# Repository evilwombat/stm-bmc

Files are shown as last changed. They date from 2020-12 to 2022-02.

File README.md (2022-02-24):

# Summary

## What is bubble memory?
[Bubble memory](https://en.wikipedia.org/wiki/Bubble_memory]) is an archaic (yet super awesome) type of nonvolatile computer memory. It stores data as a pattern of magnetization on the surface of a crystal, in a manner loosely similar to a magnetic hard drive. The amazing thing about bubble memory is that despite being magnetic in nature, it uses **no moving parts**. Unlike a magnetic hard drive, the storage medium stays in place, but the *data* moves along its surface. This is accomplished through some magical properties of the [crystal](https://en.wikipedia.org/wiki/Gadolinium_gallium_garnet) involved. Bubble memory was a promising new storage technology in the 70s and 80s, due to (at the time) impressive densities, though it was ultimately replaced by cheaper and more reliable flash memories. 

## What is this project?
This is a controller for Bubble Memory modules made by Texas Instruments in the 1980s. I have brought this up using TIB S0004 memory modules. This is a reasonably functional controller, capable of reading, erasing, and writing data, though some of the analog circuitry could probably use some refinement. This was a quarantine project so I had to start with what I had at the time.

## Demo videos (click to play)

PCB version: http://www.youtube.com/watch?v=yxEgAI12R1k
Click to play (http://www.youtube.com/watch?v=yxEgAI12R1k "PCB version")

PCB (with explanation): http://www.youtube.com/watch?v=7U3c4cfQvKs
Click to play (http://www.youtube.com/watch?v=7U3c4cfQvKs "PCB version, with explanation")

Original, breadboarded version: http://www.youtube.com/watch?v=vP2biZnxT7Y
Click to play (http://www.youtube.com/watch?v=vP2biZnxT7Y "Breadboard version")

Honestly, I can't believe the breadboard version even worked cleanly enough for bringup. Notice the sense amplifier on a separate PCB.

## Implementation

Since bubble memory modules lack an internal controller, a fair amount of external circuitry is needed to produce the carefully-timed constant-current pulses needed to run them, and to amplify/process the output of the bubble detector. Historically, the timing of the control pulses was generated by a pile of logic circuits, or by a microsequencer. Later, both Intel and TI released some ICs to assist with this. Although today these are largely unobtanium, some documentation survives, including an [early design document](Research/DevelcoReport.pdf) that predates the existence of the integrated controller. The discrete-transistor implementation of the function pulse generator (and the associated timing information) found in this document is what made this project possible.

In modern times, the digital portion of such a controller can be reasonably implemented using a regular microcontroller, in this case, an STM32F103. The state machine and timing logic is handled entirely in firmware, but a fair amount of external circuitry is still needed to convert the logic-level signals into coil drive pulses and/or constant-current "function" pulses that are fed into the bubble module itself.

The STM32 firmware implements the following:
* Bubble function timing generator (Generate/Annihilate/Transfer)
* Coil drive timing generator
* Major/minor loop state machine
* Basic loop tests, for bringup/tuning of the analog circuit
* Block I/O layer (with CRC and trivial block redundancy)
* UI layer (LCD, fonts, graphics, rotary encoder)
* Bootloader to actually load code from the bubble memory and run it
* Proof-of-concept payload that can be loaded and booted
* [Morning Music](https://www.youtube.com/watch?v=tEueYGq2mT4) (obviously)

Although historical documentation exists, most of the detailed information pertains to an earlier prototype of TI bubble memory (TBM0101), one that was ultimately not commercialized. In the more widely-available parts (such as TIB0203 and the TIB-S0004 used here), some of the key operating parameters (such as drive cycle timings and function timings) have changed substantially. The correct parameters needed to be determined partly by trial and error, and partly by translating some old Russian datasheets relating to their knockoffs of TI's more modern bubble memory parts.

## Hardware Gallery

Assembled PCB version:
Assembled PCB running

Schematic:
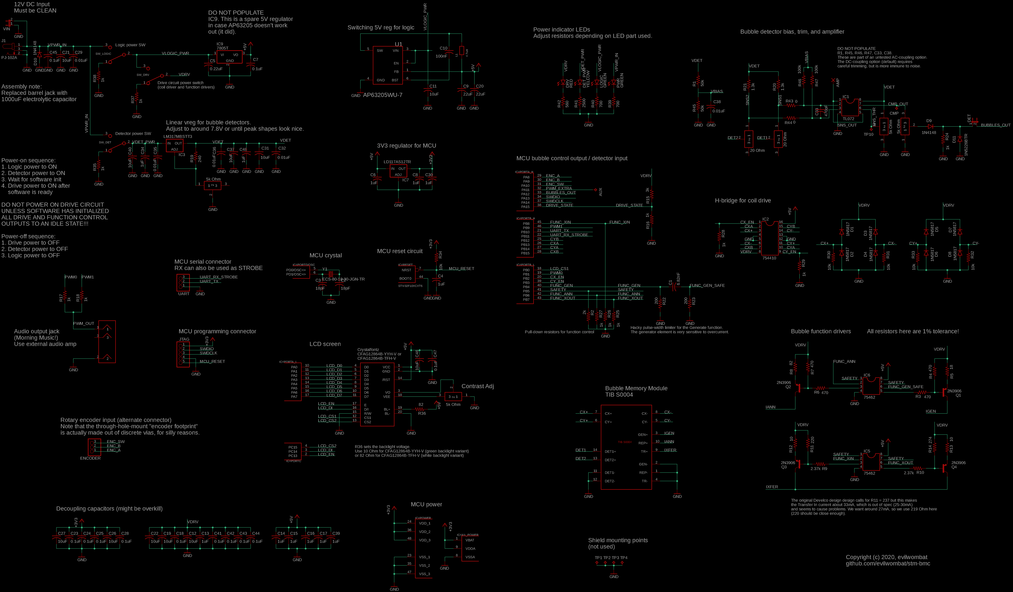
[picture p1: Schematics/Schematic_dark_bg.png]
Schematic


PCB layout:
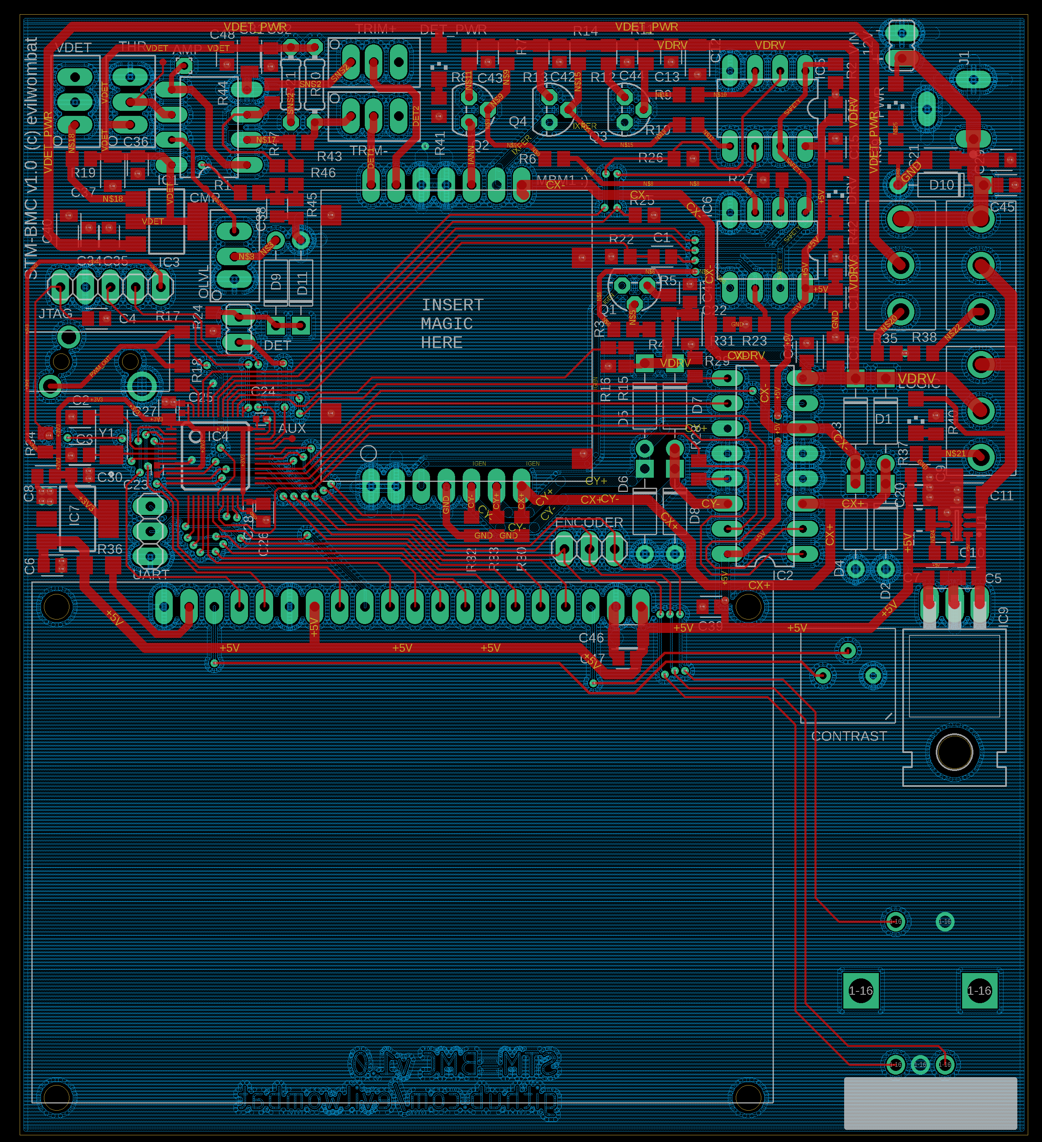
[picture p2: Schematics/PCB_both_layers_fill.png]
PCB Layout


First breadboarded version:
Full setup with breadboard

Close-up up of the breadboarded analog section. The amplifier circuit is too sensitive for breadboarding, and was built on a piece of perf-board. An alternate amplifier design would be less sensitive to minor variations in detector resistance, and hence would not need to many trimpots. But this design would be more sensitive to noise (which was much harder to control in a setup like this).
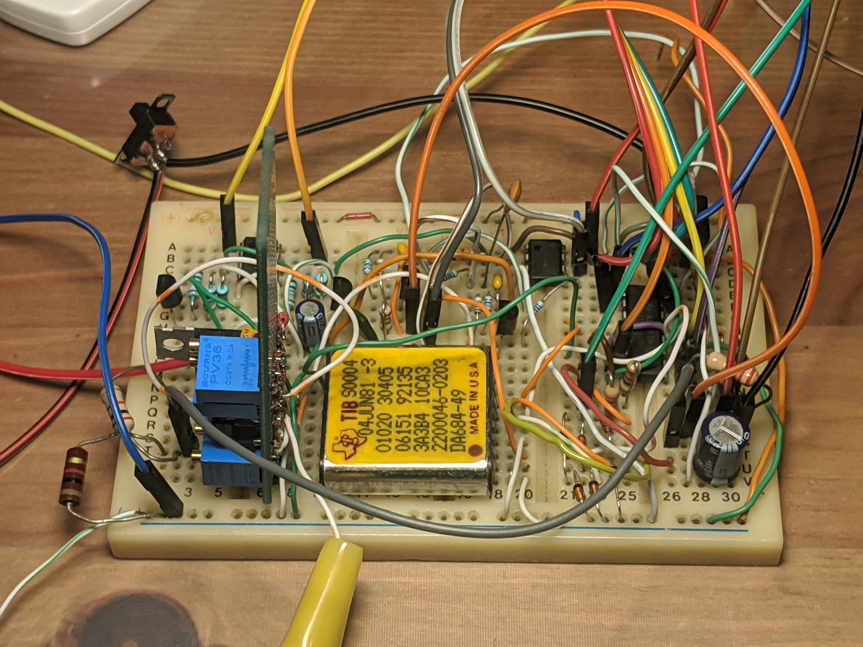
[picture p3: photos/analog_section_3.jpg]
Breadboard closeup


Some of the first bubbles!
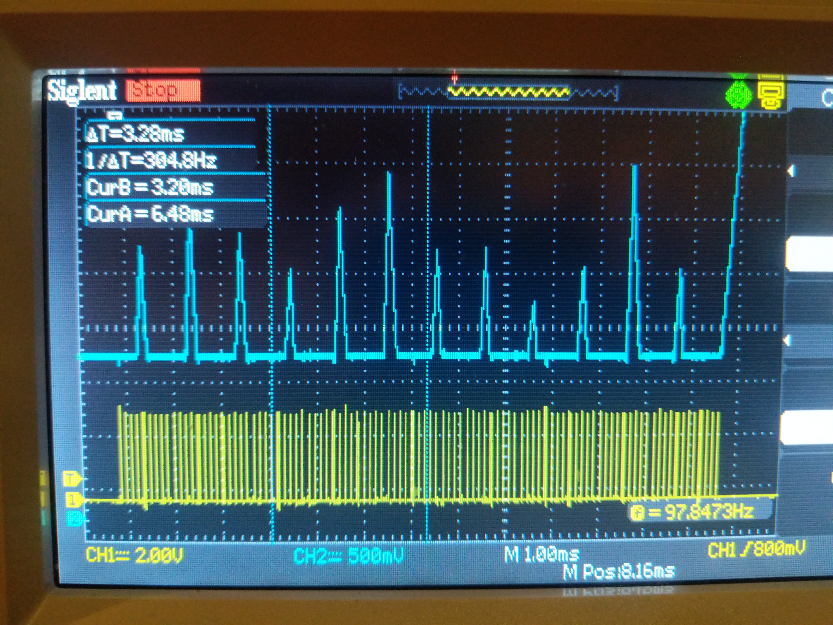
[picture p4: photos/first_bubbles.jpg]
Scope bubble trace


## What's with the music and countdown?

Perhaps the best-known example of a bubble memory design is Konami's famous [Bubble System](https://en.wikipedia.org/wiki/Bubble_System) arcade platform.

In 1985, Konami released a number of arcade machines that used bubble memory (rather than silicon ROM) for game storage. When switched on, these machines spoke a voice-based countdown while the memory modules were heated to their operating temperature. Since bubble memory is read slowly and sequentially, the game residing within was first copied into RAM before it could be executed; the machine displayed an [on-screen countdown](https://www.youtube.com/watch?v=mbM_YPyVJBE&t=175s) (and played an accompanying melody) during this process. The system was ultimately a commercial failure, because the bubble memory was expensive and very sensitive to external magnetic fields; meanwhile, silicon-based storage was growing cheaper. The few games that used this system were eventually re-released on ROM, but some original bubble-based systems survive to this day. 

<b>Fun fact:</b> The melody that played during the loading countdown was called the Morning Music, because it played every morning when the arcade operator switched on the machine. It has been said that the boot process was a kind of special / unusual thing to see, and that people would show up bright and early to the arcade just to watch the machines boot (and to listen to the morning music).

> Written with [StackEdit](https://stackedit.io/).

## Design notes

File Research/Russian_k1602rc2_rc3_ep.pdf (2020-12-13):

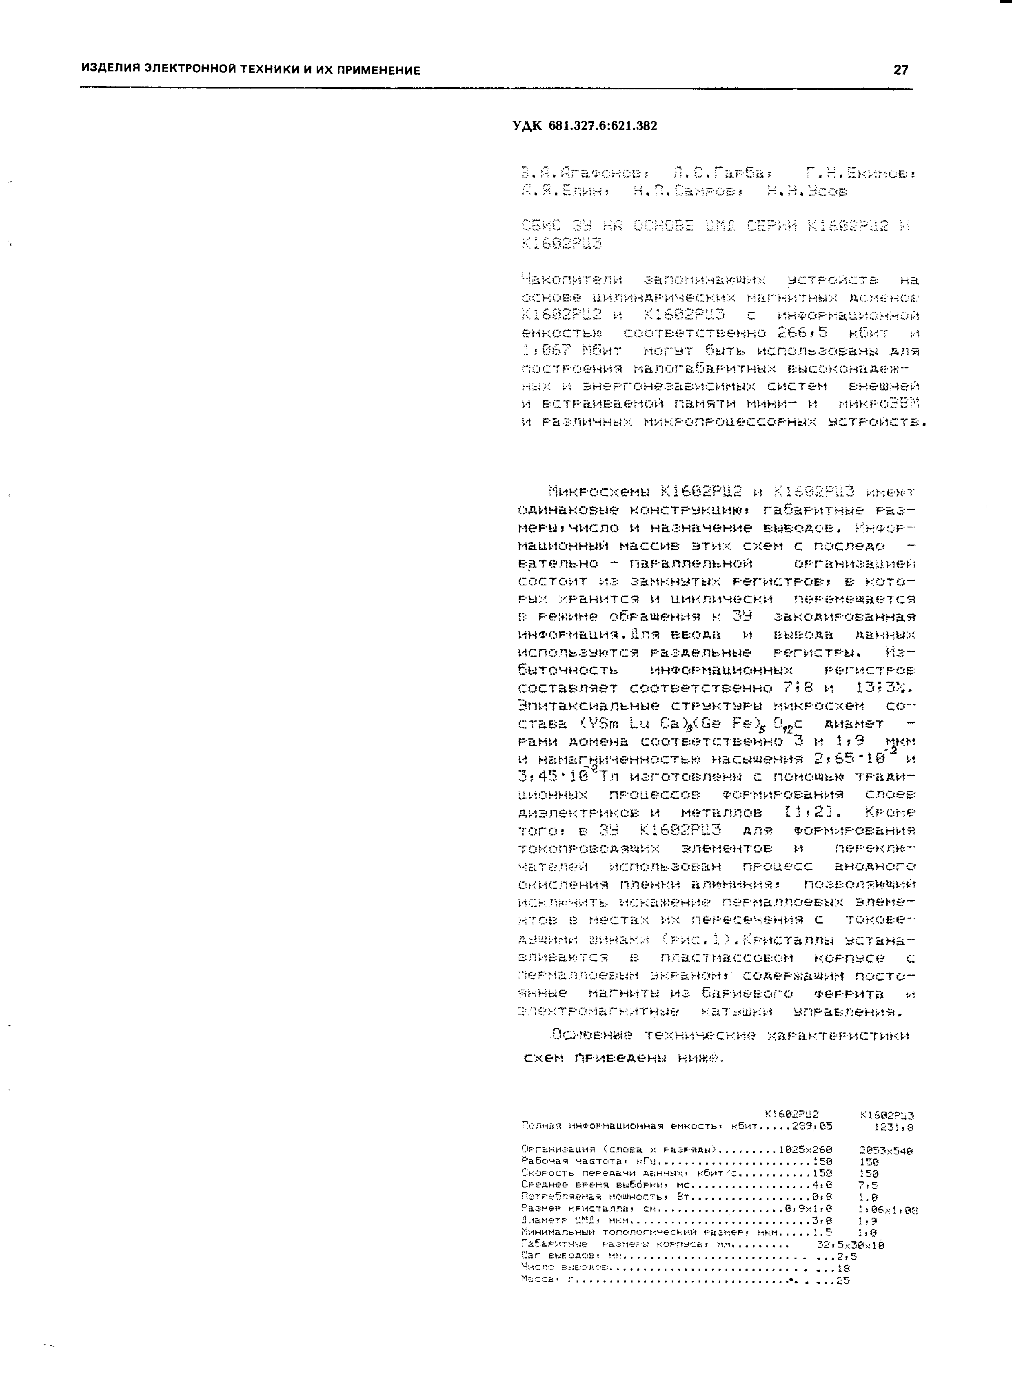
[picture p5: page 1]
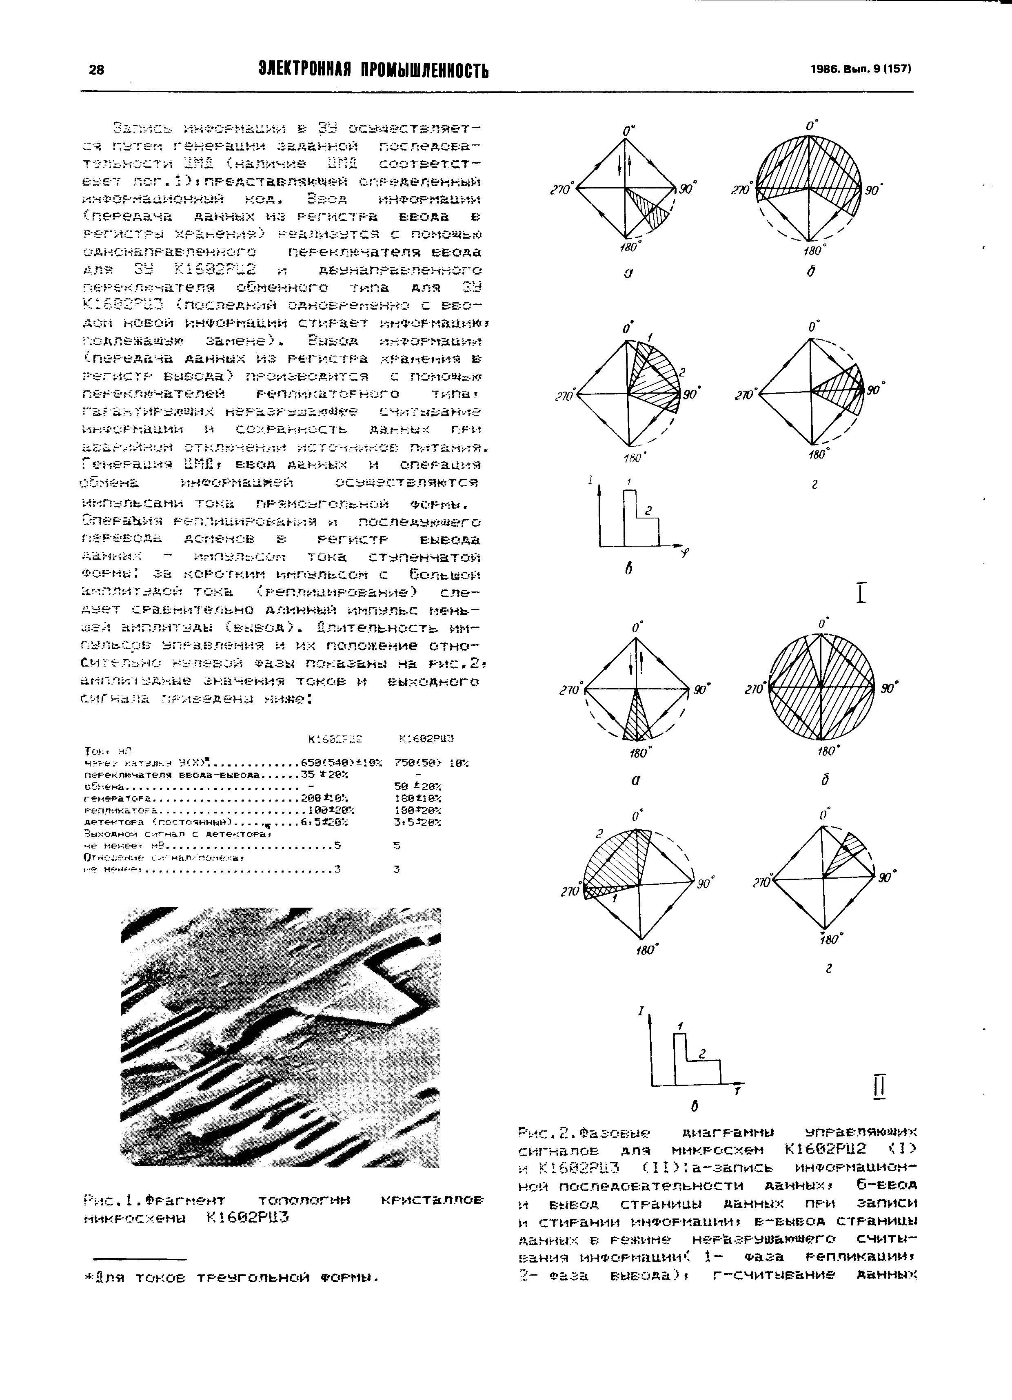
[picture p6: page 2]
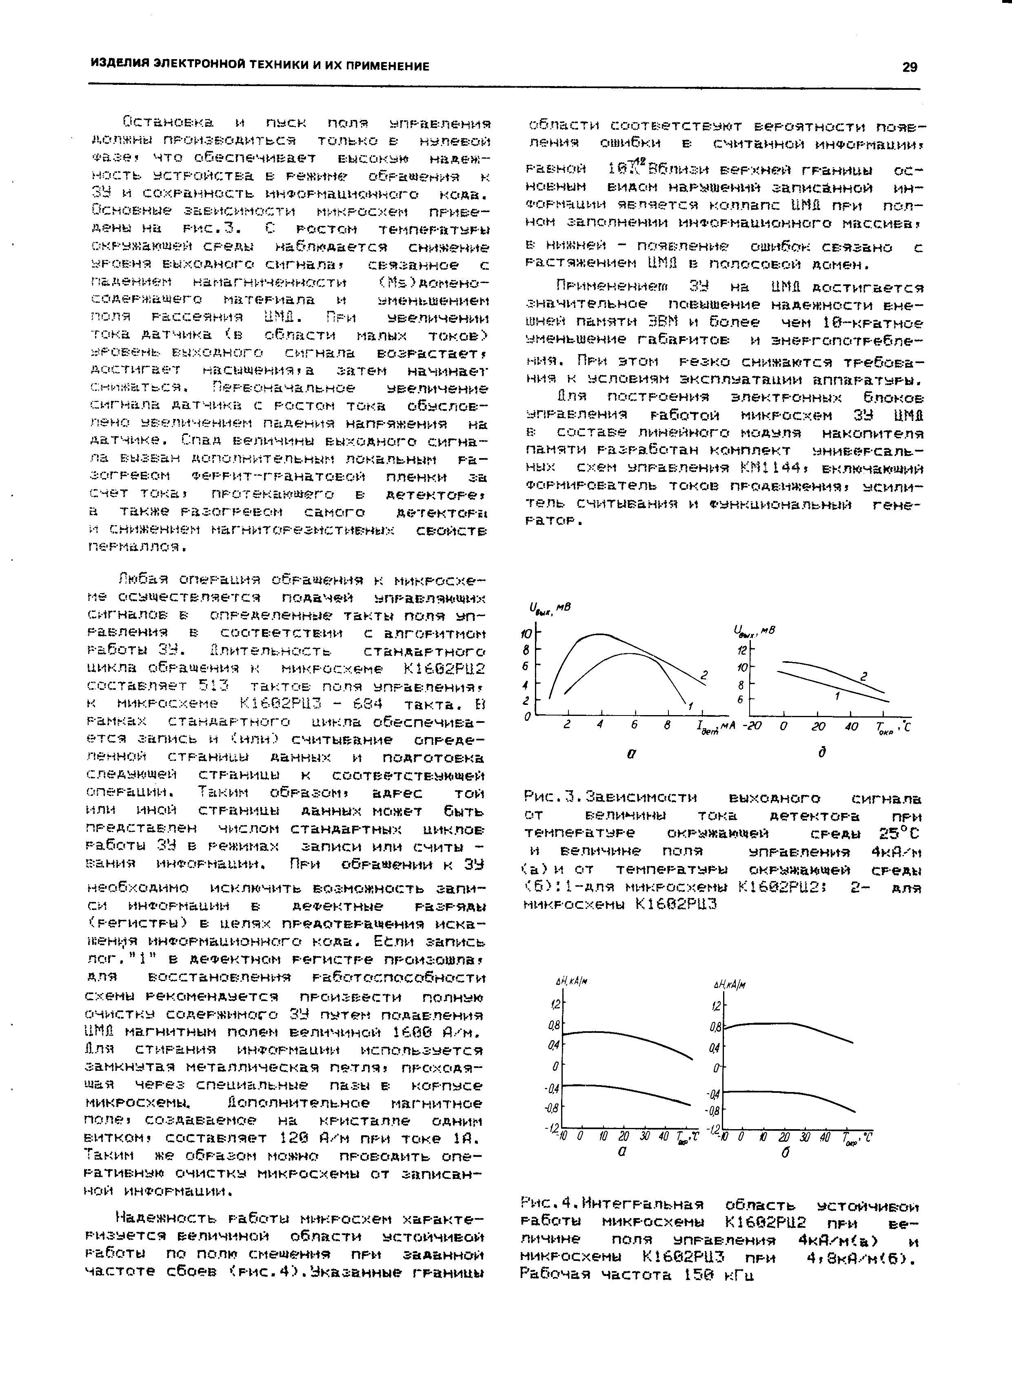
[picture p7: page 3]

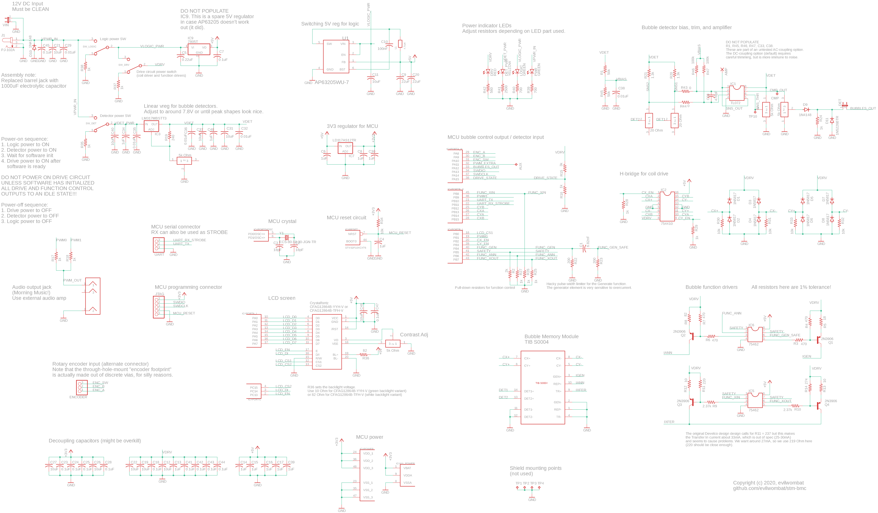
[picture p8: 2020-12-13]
Schematics/Schematic_light_bg.png

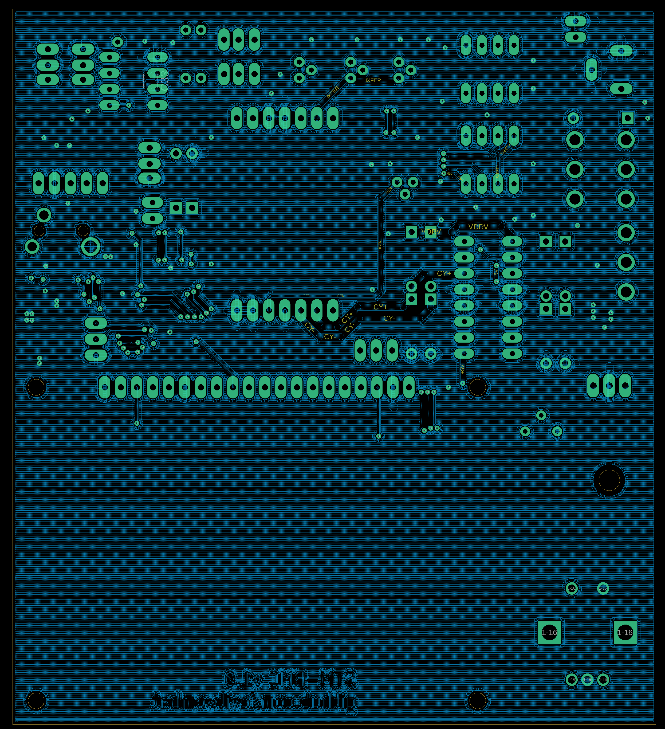
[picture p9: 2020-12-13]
Schematics/PCB_bottom_layer.png

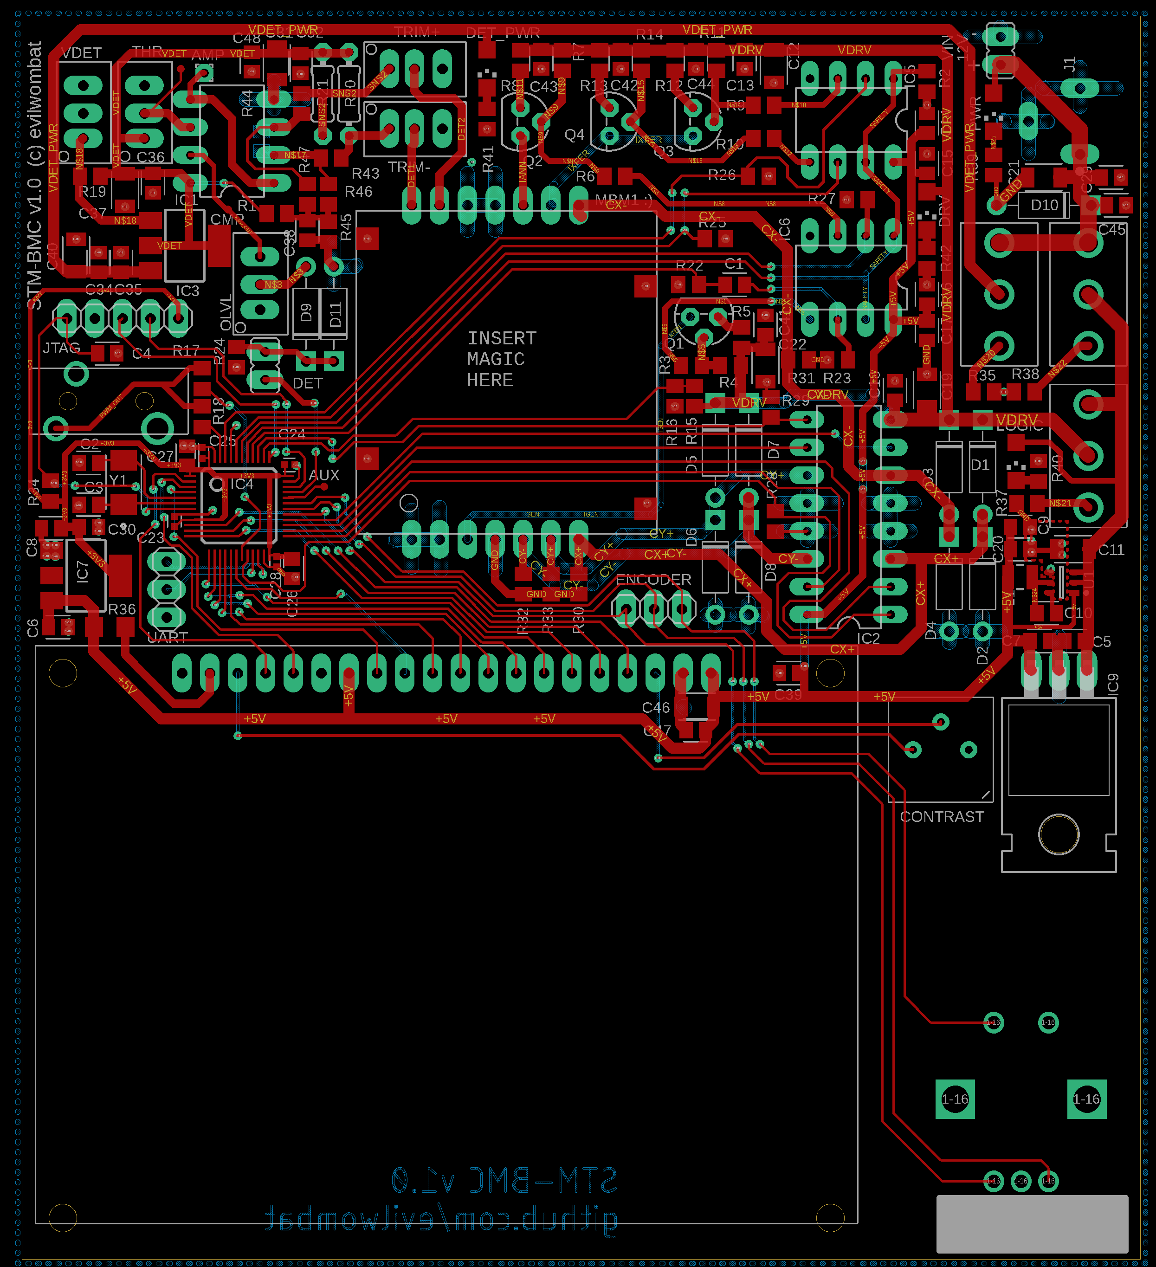
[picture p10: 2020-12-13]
Schematics/PCB_both_layers_nofill.png

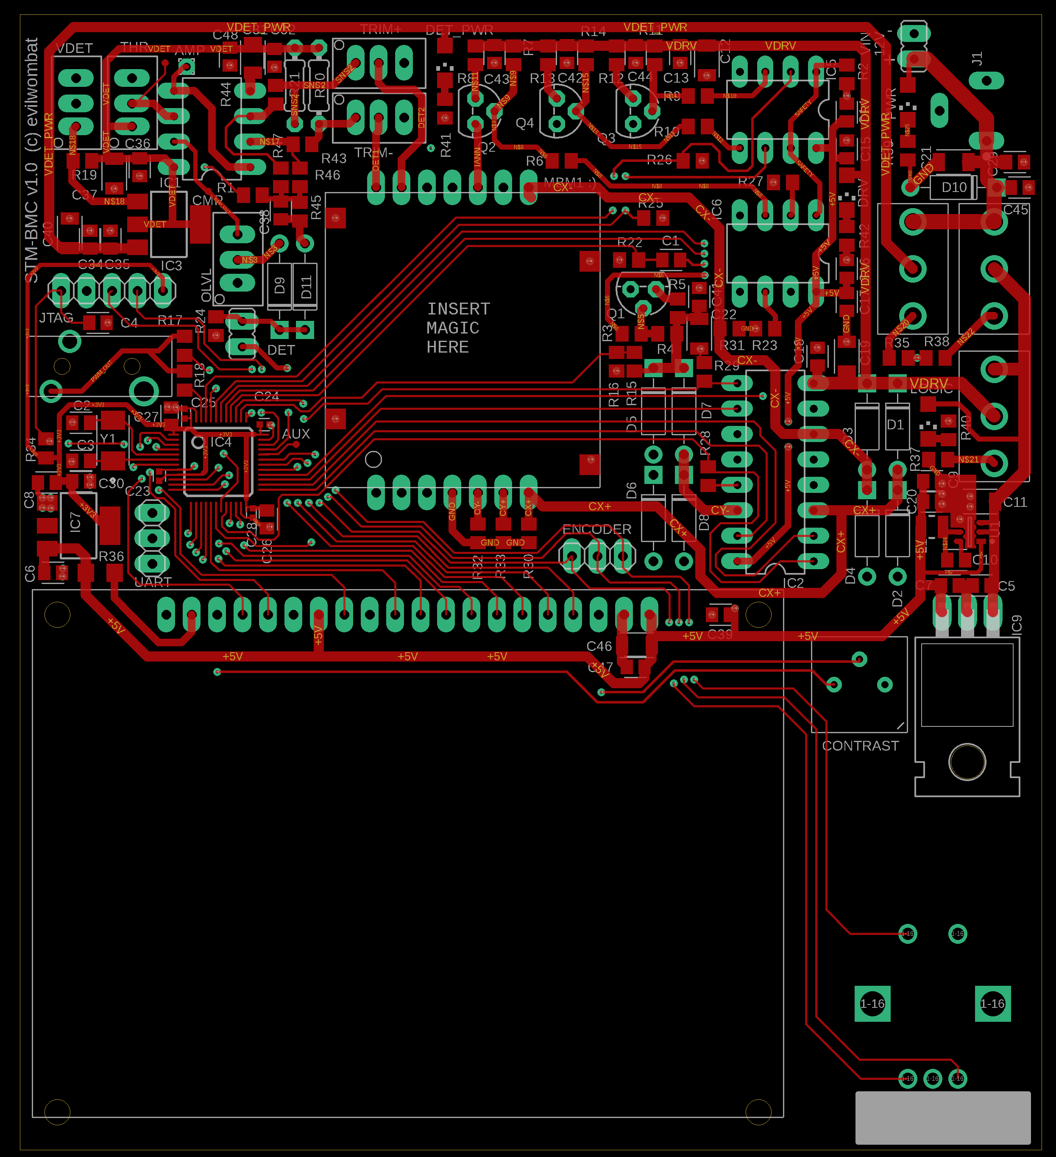
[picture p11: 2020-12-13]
Schematics/PCB_top_layer.png

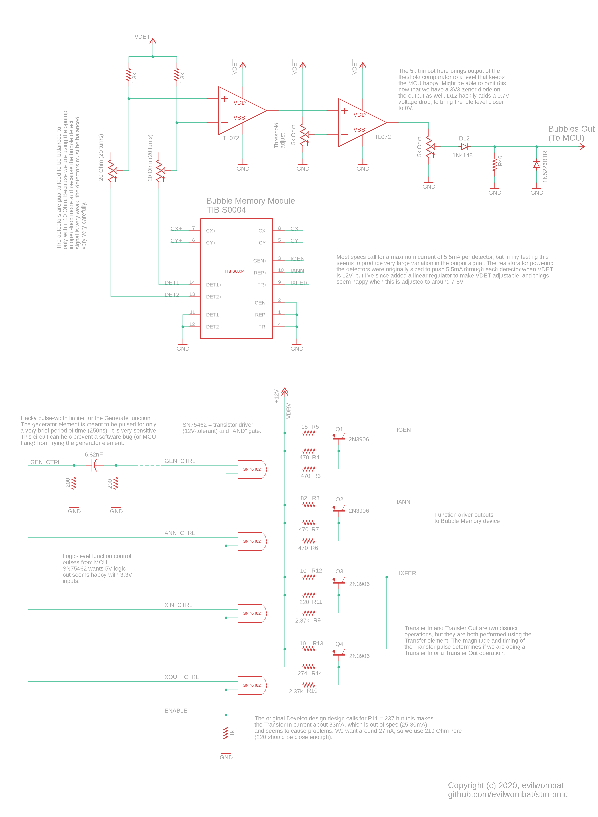
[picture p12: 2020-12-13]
Schematics/drive_circuit_annotations.png

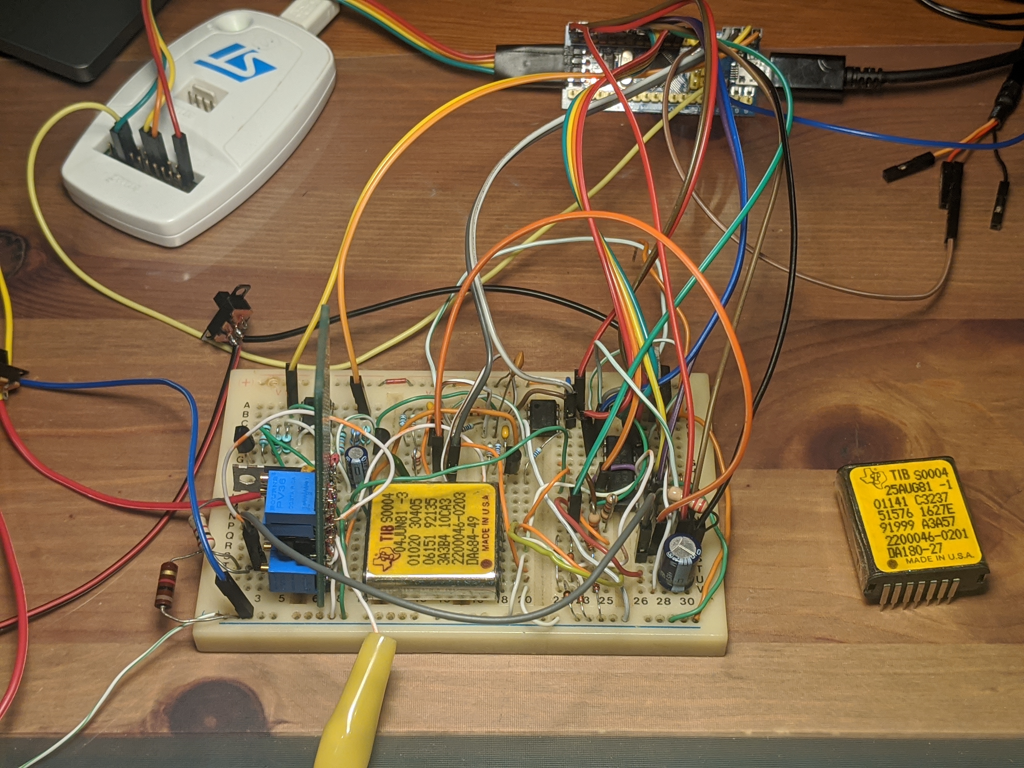
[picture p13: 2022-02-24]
photos/analog_with_stm.jpg

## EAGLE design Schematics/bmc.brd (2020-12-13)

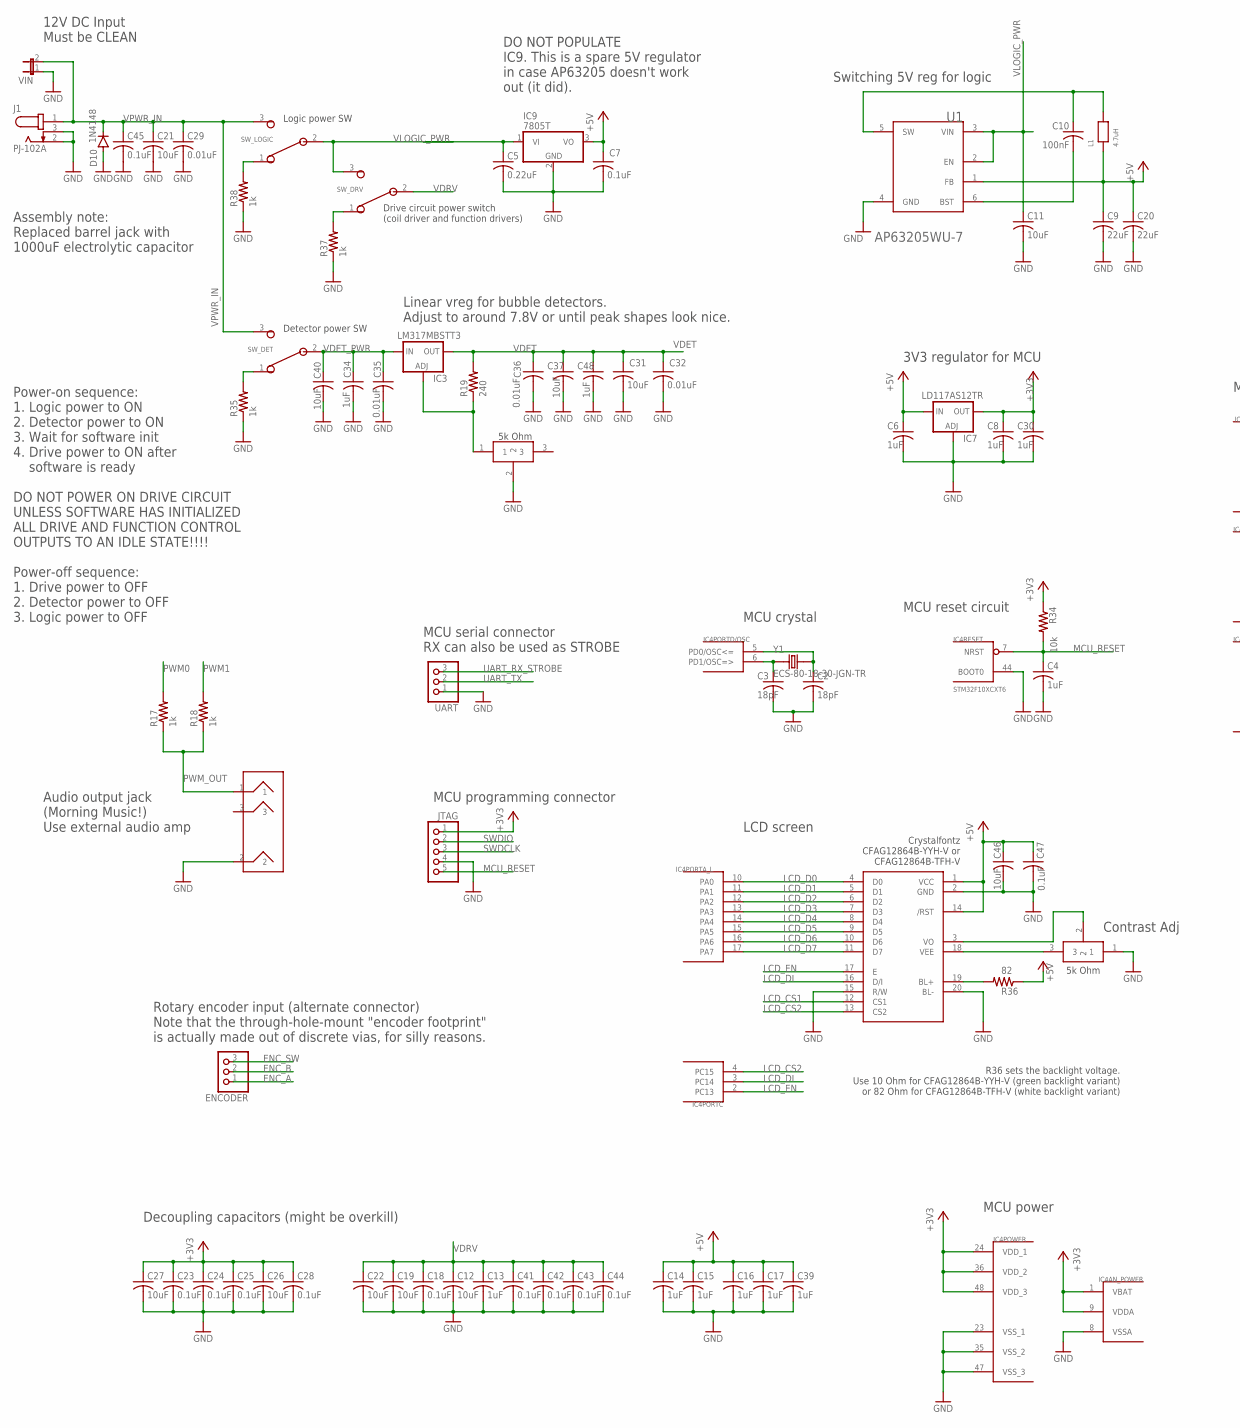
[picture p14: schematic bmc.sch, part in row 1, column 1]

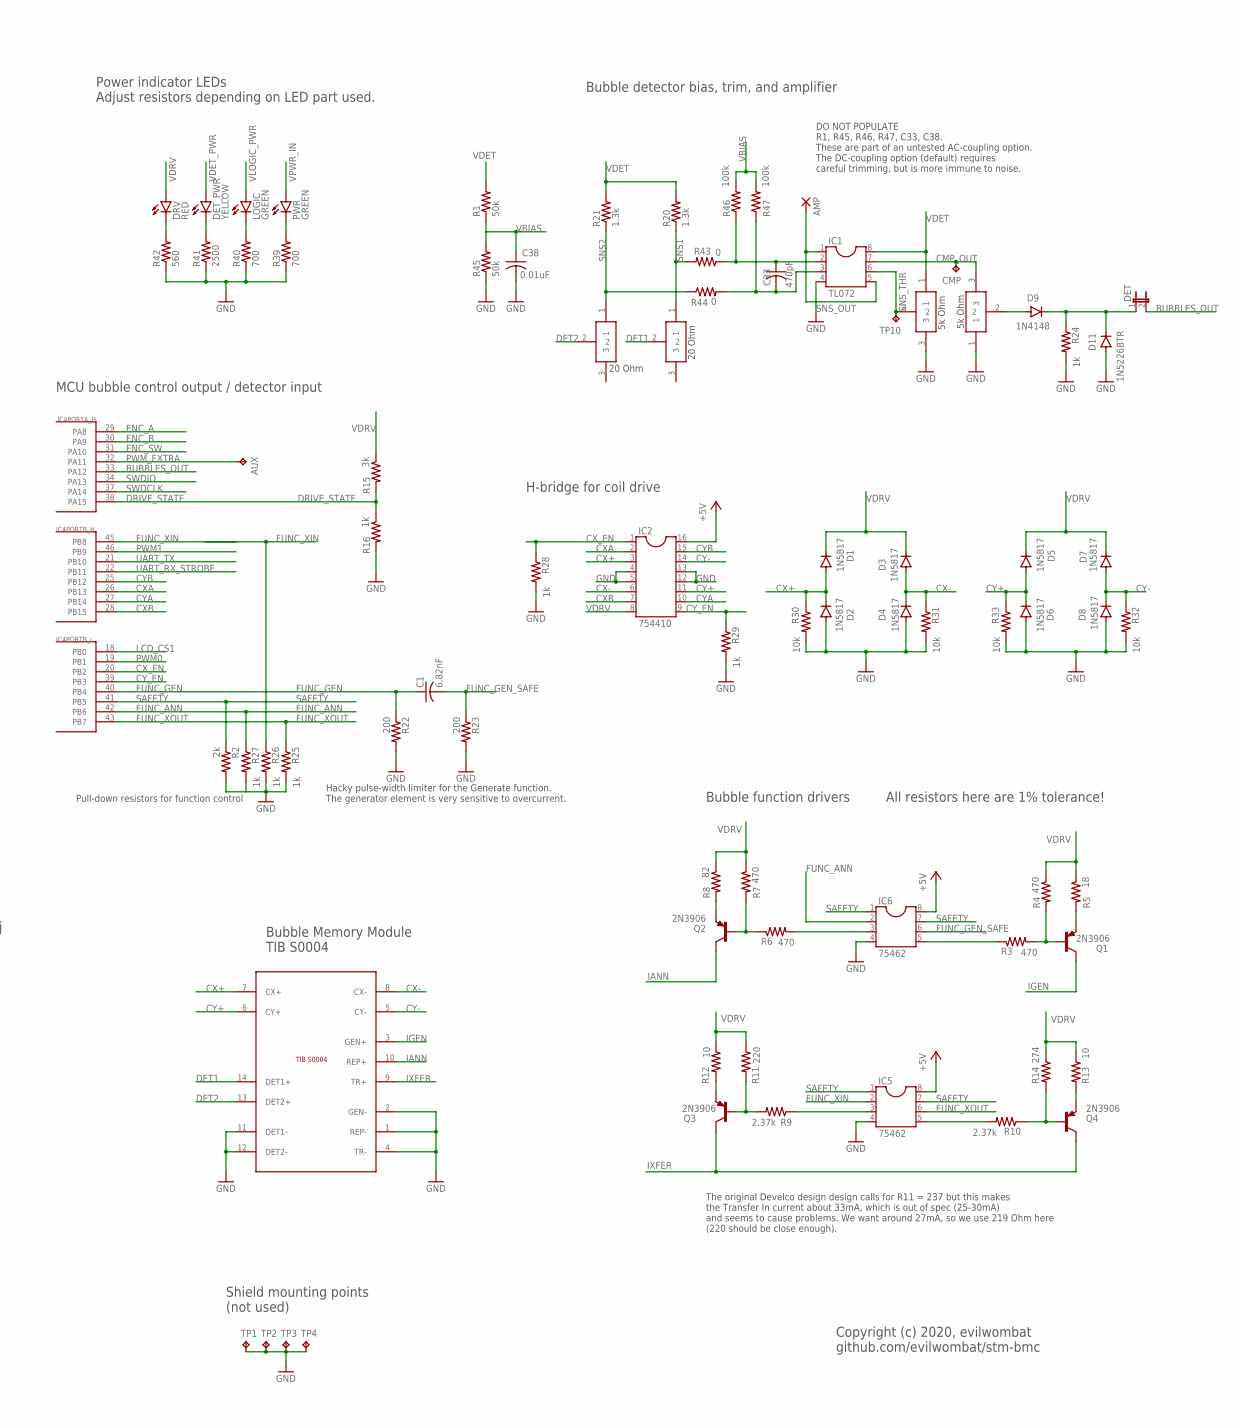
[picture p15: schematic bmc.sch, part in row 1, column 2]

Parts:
AMP: 1,6/0,8
AUX: TPTP07R; TP07R
C1: 6.82nF; CAPC2012X110
C2, C3: 18pF; CAPC2012X110
C4, C6, C8, C13, C14, C15, C16, C17, C30, C34, C39, C48: 1uF; CAPC2012X110
C5: 0.22uF; CAPC2012X110
C7, C18, C41, C42, C43, C44, C45, C47: 0.1uF; CAPC2012X110
C9, C20: 22uF; CAPC2012X110
C10: 100nF; CAPC2012X110
C11, C12, C19, C21, C22, C31, C37, C40, C46: 10uF; CAPC3216X135
C23, C24, C25, C28: 0.1uF; CAPC1005X60
C26, C27: 10uF; CAPC2012X110
C29, C32, C35, C36, C38: 0.01uF; CAPC2012X110
C33: 470pF; CAPC2012X110
CMP: TPTP07R; TP07R
D1, D2, D3, D4, D5, D6, D7, D8: 1N5817; DO-41
D9, D10: 1N4148; DO-41
D11: 1N5226BTR; DO-41
DET: JP1E; JP1
DET_PWR: YELLOW; CHIPLED_1206
DISP1: CFAG12864B; CFAG16864B
DRV: RED; CHIPLED_1206
ENCODER: PINHD-1X3; 1X03
IC1: TL072; DIL08
IC2: 754410; DIL16
IC3: LM317MBSTT3; SOT223
IC4: STM32F10XCXT6; TQFP48
IC5, IC6: 75462; DIL08
IC7: LD117AS12TR; SOT223
IC9: 7805T; TO220H
J1: PJ-102A; CUI_PJ-102A
JTAG: PINHD-1X5; 1X05
L1: 4.7uH; WE-PMI_1008
LOGIC: GREEN; CHIPLED_1206
MUSIC_OUT: STX-3501-3N
OLVL: PV36W
PWR: GREEN; CHIPLED_1206
Q1, Q2, Q3, Q4: 2N3906; TO92
R1, R45: 50k; R0805
R2: 2k; R0805
R3, R4, R6, R7: 470; R0805
R5: 18; R0805
R8: 82; R0805
R9, R10: 2.37k; R0805
R11: 220; R0805
R12, R13: 10; R0805
R14: 274; R0805
R15: 3k; R0805
R16, R17, R18, R24, R25, R26, R27, R28, R29, R35, R37, R38: 1k; R0805
R19: 240; R0805
R20, R21: 1.3k; 0204/7
R22, R23: 200; R0805
R30, R31, R32, R33, R34: 10k; R0805
R36: 82; R1206
R39, R40: 700; R0805
R41: 2500; R0805
R42: 560; R0805
R43, R44: 0; R0805
R46, R47: 100k; R0805
SW_DET: SW_SPDT
SW_DRV: SW_SPDT
SW_LOGIC: SW_SPDT
THR: PV36W
TP1, TP2, TP3, TP4: TPTP20SQ; TP20SQ
TP10: TPTP07R; TP07R
TRIM+: PV36W
TRIM-: 20 Ohm; PV36W
U1: DIODES_INC._AP63205WU-7DIODES_INC._AP63205WU-7_0_3; DIODES_INC._AP63205WU-7_3
U$1: TP3386; 3386-EY5
U$5: TIB_S0004; MBM
UART: PINHD-1X3; 1X03
VDET: PV36W
VIN: JP1E; JP1
Y1: ECS-80-18-30-JGN-TR; XTAL_ECS-80-18-30-JGN-TR

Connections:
+3V3: C8.1, C23.1, C24.1, C25.1, C26.1, C27.1, C28.1, C30.1, IC4.1 (VBAT), IC4.9 (VDDA), IC4.24 (VDD_1), IC4.36 (VDD_2), IC4.48 (VDD_3), IC7.4 (OUT), JTAG.1, R34.1
+5V: C6.1, C7.1, C9.1, C14.1, C15.1, C16.1, C17.1, C20.1, C39.1, C46.1, C47.1, DISP1.1 (VCC), DISP1.14 (/RST), IC2.16, IC5.8, IC6.8, IC7.3 (IN), IC9.3 (VO), L1.1, R36.1, U1.1 (FB)
BUBBLES_OUT: DET.2, IC4.33 (PA12)
BUBBLES_OUT_JP: D9.C, D11.C, DET.1, R24.1
CMP_OUT: CMP.TP, IC1.7, OLVL.3
CX+: D1.A, D2.C, IC2.3, R30.1, U$5.7 (CX+)
CX-: D3.A, D4.C, IC2.6, R31.1, U$5.8 (CX-)
CXA: IC2.2, IC4.26 (PB13)
CXB: IC2.7, IC4.28 (PB15)
CX_EN: IC2.1, IC4.20 (PB2), R28.1
CY+: D5.A, D6.C, IC2.11, R33.1, U$5.6 (CY+)
CY-: D7.A, D8.C, IC2.14, R32.1, U$5.5 (CY-)
CYA: IC2.10, IC4.27 (PB14)
CYB: IC2.15, IC4.25 (PB12)
CY_EN: IC2.9, IC4.39 (PB3), R29.1
DET1: TRIM-.2, U$5.14 (DET1+)
DET2: TRIM+.2, U$5.13 (DET2+)
DRIVE_STATE: IC4.38 (PA15), R15.2, R16.1
ENC_A: ENCODER.1, IC4.29 (PA8)
ENC_B: ENCODER.2, IC4.30 (PA9)
ENC_SW: ENCODER.3, IC4.31 (PA10)
FUNC_ANN: IC4.42 (PB6), IC6.2, R27.1
FUNC_GEN: C1.1, IC4.40 (PB4), R22.1
FUNC_GEN_SAFE: C1.2, IC6.6, R23.1
FUNC_XIN: IC4.45 (PB8), IC5.2, R26.1
FUNC_XOUT: IC4.43 (PB7), IC5.6, R25.1
GND: C2.2, C3.2, C4.2, C5.2, C6.2, C7.2, C8.2, C9.2, C11.2, C12.2, C13.2, C14.2, C15.2, C16.2, C17.2, C18.2, C19.2, C20.2, C21.2, C22.2, C23.2, C24.2, C25.2, C26.2, C27.2, C28.2, C29.2, C30.2, C31.2, C32.2, C34.2, C35.2, C36.2, C37.2, C38.2, C39.2, C40.2, C41.2, C42.2, C43.2, C44.2, C45.2, C46.2, C47.2, C48.2, D2.A, D4.A, D6.A, D8.A, D10.A, D11.A, DISP1.2 (GND), DISP1.15 (R/W), DISP1.20 (BL-), IC1.4, IC2.4, IC2.5, IC2.12, IC2.13, IC4.8 (VSSA), IC4.23 (VSS_1), IC4.35 (VSS_2), IC4.44 (BOOT0), IC4.47 (VSS_3), IC5.4, IC6.4, IC7.1 (ADJ), IC9.2 (GND), J1.2, J1.3, JTAG.4, MUSIC_OUT.2, OLVL.1, R2.2, R16.2, R22.2, R23.2, R24.2, R25.2, R26.2, R27.2, R28.2, R29.2, R30.2, R31.2, R32.2, R33.2, R35.1, R37.1, R38.1, R39.1, R40.1, R41.1, R42.1, R45.1, THR.3, TP1.TP, TP2.TP, TP3.TP, TP4.TP, U1.4 (GND), U$1.1, U$5.1 (REP-), U$5.2 (GEN-), U$5.4 (TR-), U$5.11 (DET1-), U$5.12 (DET2-), UART.1, VDET.2, VIN.1
IANN: Q2.1 (C), U$5.10 (REP+)
IGEN: Q1.1 (C), U$5.3 (GEN+)
IXFER: Q3.1 (C), Q4.1 (C), U$5.9 (TR+)
LCD_BL+: DISP1.19 (BL+), R36.2
LCD_CS1: DISP1.12 (CS1), IC4.18 (PB0)
LCD_CS2: DISP1.13 (CS2), IC4.4 (PC15)
LCD_D0: DISP1.4 (D0), IC4.10 (PA0)
LCD_D1: DISP1.5 (D1), IC4.11 (PA1)
LCD_D2: DISP1.6 (D2), IC4.12 (PA2)
LCD_D3: DISP1.7 (D3), IC4.13 (PA3)
LCD_D4: DISP1.8 (D4), IC4.14 (PA4)
LCD_D5: DISP1.9 (D5), IC4.15 (PA5)
LCD_D6: DISP1.10 (D6), IC4.16 (PA6)
LCD_D7: DISP1.11 (D7), IC4.17 (PA7)
LCD_DI: DISP1.16 (D/I), IC4.3 (PC14)
LCD_EN: DISP1.17 (E), IC4.2 (PC13)
LCD_VEE: DISP1.18 (VEE), U$1.3
LCD_VO: DISP1.3 (VO), U$1.2
MCU_RESET: C4.1, IC4.7 (NRST), JTAG.5, R34.2
unnamed: C3.1, IC4.6 (PD1/OSC=>), Y1.1 (IN/OUT)
unnamed: C2.1, IC4.5 (PD0/OSC<=), Y1.2 (OUT/IN)
unnamed: D9.A, OLVL.2
unnamed: C33.2, IC1.3, R44.2, R47.1
unnamed: Q1.2 (B), R3.2, R4.2
unnamed: IC6.5, R3.1
unnamed: Q1.3 (E), R5.2
unnamed: IC6.3, R6.2
unnamed: Q2.2 (B), R6.1, R7.2
unnamed: IC5.3, R9.1
unnamed: Q2.3 (E), R8.2
unnamed: IC5.5, R10.2
unnamed: Q3.3 (E), R12.2
unnamed: Q3.2 (B), R9.2, R11.2
unnamed: Q4.2 (B), R10.1, R14.2
unnamed: Q4.3 (E), R13.2
unnamed: C33.1, IC1.2, R43.1, R46.1
unnamed: IC3.1 (ADJ), R19.1, VDET.1
unnamed: R35.2, SW_DET.1 (NC)
unnamed: R37.2, SW_DRV.1 (NC)
unnamed: R38.2, SW_LOGIC.1 (NC)
unnamed: C10.1, L1.2, U1.5 (SW)
unnamed: PWR.C, R39.2
unnamed: LOGIC.C, R40.2
unnamed: DET_PWR.C, R41.2
unnamed: DRV.C, R42.2
unnamed: C10.2, U1.6 (BST)
PWM0: IC4.19 (PB1), R17.2
PWM1: IC4.46 (PB9), R18.2
PWM_EXTRA: AUX.TP, IC4.32 (PA11)
PWM_OUT: MUSIC_OUT.1, R17.1, R18.1
SAFETY: IC4.41 (PB5), IC5.1, IC5.7, IC6.1, IC6.7, R2.1
SNS1: R20.1, R43.2, TRIM-.1
SNS2: R21.1, R44.1, TRIM+.1
SNS_OUT: AMP.1, IC1.1, IC1.5
SNS_THR: IC1.6, THR.2, TP10.TP
SWDCLK: IC4.37 (PA14), JTAG.3
SWDIO: IC4.34 (PA13), JTAG.2
UART_RX_STROBE: IC4.22 (PB11), UART.3
UART_TX: IC4.21 (PB10), UART.2
VBIAS: C38.1, R1.1, R45.2, R46.2, R47.2
VDET: C31.1, C32.1, C36.1, C37.1, C48.1, IC1.8, IC3.2 (OUT), IC3.4 (OUT), R1.2, R19.2, R20.2, R21.2, THR.1
VDET_PWR: C34.1, C35.1, C40.1, DET_PWR.A, IC3.3 (IN), SW_DET.2 (COM)
VDRV: C12.1, C13.1, C18.1, C19.1, C22.1, C41.1, C42.1, C43.1, C44.1, D1.C, D3.C, D5.C, D7.C, DRV.A, IC2.8, R4.1, R5.1, R7.1, R8.1, R11.1, R12.1, R13.1, R14.1, R15.1, SW_DRV.2 (COM)
VLOGIC_PWR: C5.1, C11.1, IC9.1 (VI), LOGIC.A, SW_DRV.3 (NO), SW_LOGIC.2 (COM), U1.2 (EN), U1.3 (VIN)
VPWR_IN: C21.1, C29.1, C45.1, D10.C, J1.1, PWR.A, SW_DET.3 (NO), SW_LOGIC.3 (NO), VIN.2

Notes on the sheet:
The original Develco design design calls for R11 = 237 but this makes the Transfer In current about 33mA, which is out of spec (25-30mA) and seems to cause problems. We want around 27mA, so we use 219 Ohm here (220 should be close enough).
DO NOT POPULATE R1, R45, R46, R47, C33, C38. These are part of an untested AC-coupling option. The DC-coupling option (default) requires careful trimming, but is more immune to noise.
5k Ohm
20 Ohm
DO NOT POPULATE IC9. This is a spare 5V regulator in case AP63205 doesn't work out (it did).
Switching 5V reg for logic
3V3 regulator for MCU
Linear vreg for bubble detectors. Adjust to around 7.8V or until peak shapes look nice.
Logic power SW
Detector power SW
Drive circuit power switch (coil driver and function drivers)
12V DC Input Must be CLEAN
Power indicator LEDs Adjust resistors depending on LED part used.
Audio output jack (Morning Music!) Use external audio amp
MCU serial connector RX can also be used as STROBE
MCU programming connector
MCU crystal
Rotary encoder input (alternate connector) Note that the through-hole-mount "encoder footprint" is actually made out of discrete vias, for silly reasons.
Decoupling capacitors (might be overkill)
LCD screen
Contrast Adj
Crystalfontz CFAG12864B-YYH-V or CFAG12864B-TFH-V
R36 sets the backlight voltage. Use 10 Ohm for CFAG12864B-YYH-V (green backlight variant) or 82 Ohm for CFAG12864B-TFH-V (white backlight variant)
Bubble detector bias, trim, and amplifier
Hacky pulse-width limiter for the Generate function. The generator element is very sensitive to overcurrent.
Pull-down resistors for function control
MCU bubble control output / detector input
MCU reset circuit
MCU power
H-bridge for coil drive
Bubble Memory Module TIB S0004
Bubble function drivers
Shield mounting points (not used)
All resistors here are 1% tolerance!
Assembly note: Replaced barrel jack with 1000uF electrolytic capacitor
Power-on sequence: 1. Logic power to ON 2. Detector power to ON 3. Wait for software init 4. Drive power to ON after software is ready DO NOT POWER ON DRIVE CIRCUIT UNLESS SOFTWARE HAS INITIALIZED ALL DRIVE AND FUNCTION CONTROL OUTPUTS TO AN IDLE STATE!!!! Power-off sequence: 1. Drive power to OFF 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
Copyright (c) 2020, evilwombat github.com/evilwombat/stm-bmc

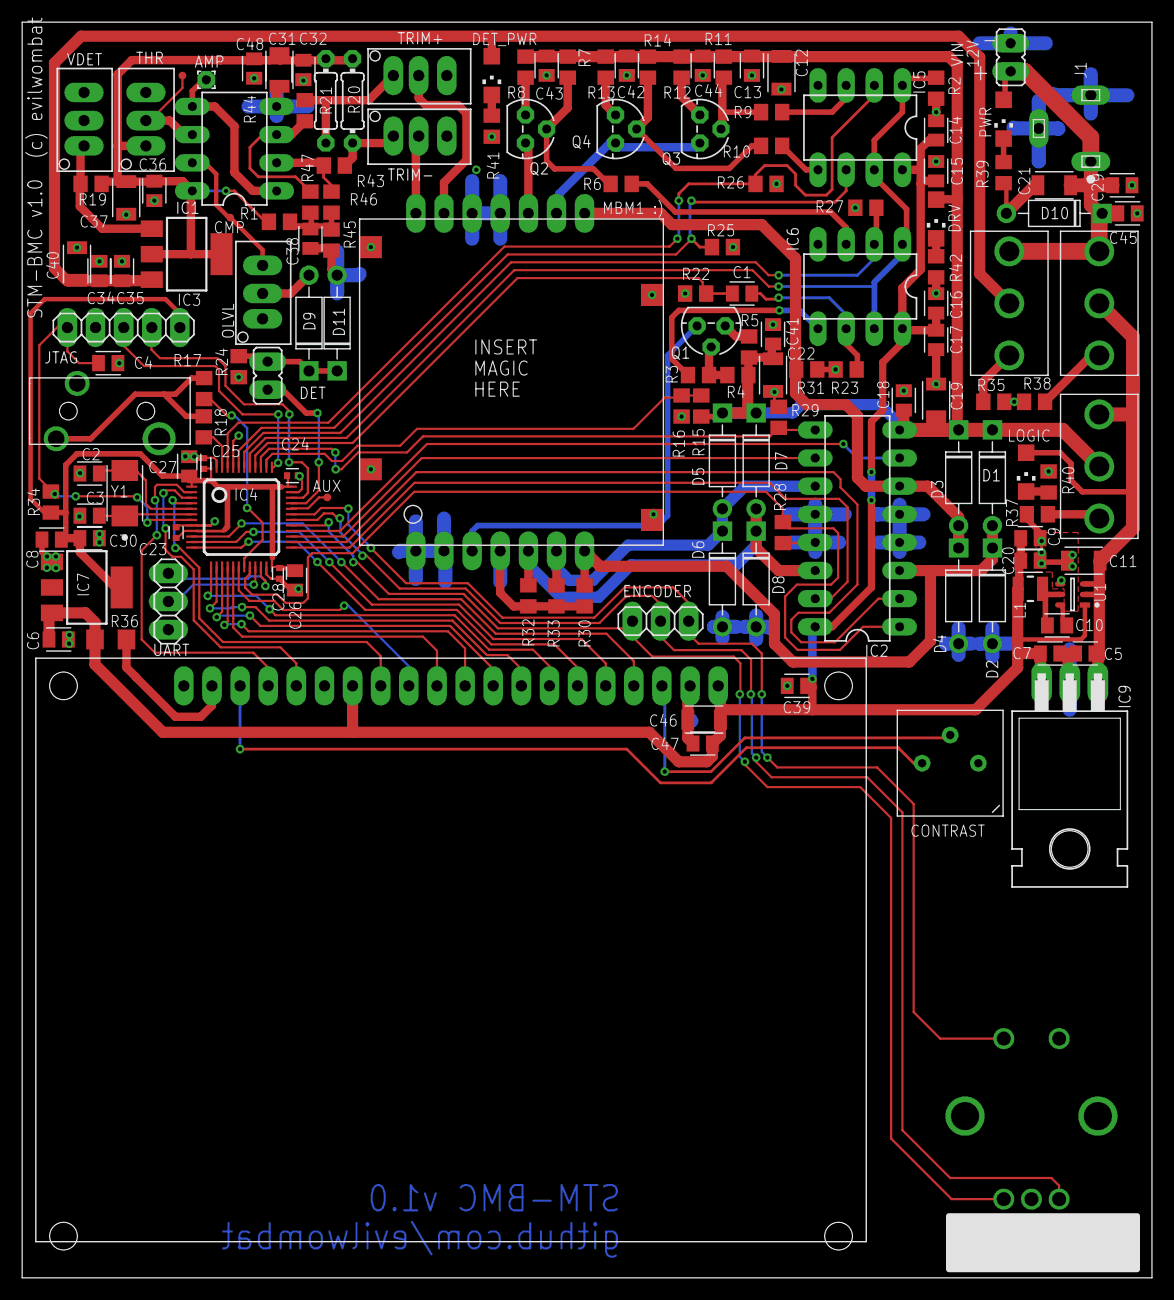
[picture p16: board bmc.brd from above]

Board: 2 copper layers, 102.0 x 113.4 mm, 151 parts (1 on the bottom side), 92 nets.

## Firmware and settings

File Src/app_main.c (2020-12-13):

/*
 * Copyright (c) 2020, evilwombat
 *
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
 */

#include <stdio.h>
#include <string.h>
#include "bitbuffer.h"
#include "block_io.h"
#include "bmc.h"
#include "sequencer.h"
#include "util.h"
#include "music.h"
#include "encoder.h"
#include "lcd.h"
#include "console.h"
#include "gfx_util.h"
#include "loader.h"
#include "selftest.h"

/* Perform a warm-up routine of the drive and related electronics.
 * This is done by repeatedly rotating the drive field, and presumably heating the device to
 * a steady-state temperature through resistive losses on the drive coils.
 * The TIB-S0004 technically does not require warm-up, but it does require some temperature
 * compensation (which we don't do). Becuase the detector circult is a bit suboptimal and
 * finnicky, it seems to benefit from some warmup as well, though technically cycling just
 * the drive coils shouldn't affect the temperature of the external detector circuit...
 */
void warm_up_drive(int quick)
{
    int i;
    int cycles = 100;

    if (quick)
        cycles = 10;

    uart_printf("Warming up the drive coils (in case that helps)\n");
    con_clear();
    con_gotoxy(19, 0);
    con_printf("WARMING UP NOW");
    for (i = cycles; i >= 0; i--) {
        gfx_draw_countdown(i);
        lcd_update();
        step_bubbles(20000);

        if (test_abort_requested()) {
            con_clear();
            con_printf("Operation aborted\n");
            bmc_shut_down();
        }
    }

    con_clear();
    con_printf("\rWarming up done!   \n");
}

/* Main menu items */
static const char *main_menu[] = {
    "Bubble memory loader",
    "Fast warmup (CAREFUL)",
    "Write new payload",
    "Run minor loop tests",
    "Run major loop test",
    NULL,
};

/* Application entry point, after CubeMX system init */
int app_main(void)
{
    int ret, choice;

    safe_drive();
    lcd_init();

    /* Inform the user if they accidentally turned on the drive before turning on the MCU */
    check_initial_drive_state();

    uart_printf("\n\n\n\n\n\n\n\n\n\n\n\n\n\n\n\n\n\n\n\n\n\n\n\n");
    uart_printf("Start\n");

    encoder_init();
    con_init();

    con_set_font(&font_3x5);
    con_clear();
    con_printf("STM32 Bubble Memory Controller\n\n");

    __enable_irq();
    HAL_Delay(200);

    /* Show a brief splash / information screen */
    bubble_storage_init();

    HAL_Delay(2000);

    while(1) {

        con_clear();
        con_set_font(&font_5x7);
        con_printf(" ARM Bubble System \\\n");
        con_set_font(&font_3x5);
        con_printf("  github.com/evilwombat");
        con_set_font(&font_5x7);

        con_gotoxy(0, 19);
        choice = run_menu(main_menu, con_cur_y());

        con_printf("\n");

        wait_for_drive_arm();

        if (choice == 0 || choice == 1) {
            music_start();
            warm_up_drive(choice == 1); /* Fast warmup? */

            uart_printf("Running detector tests...\n");

            ret = warm_up_detector();

            if (ret != 0) {
                music_stop();
                if (ret == SELFTEST_FAIL)
                    con_printf("Warm-up test failed! Check detector calibration?\n");

                bmc_shut_down();
            }

            bmc_idle();

            load_payload();
            music_stop();
            launch_payload();
            bmc_shut_down();    /* We should never get here */
            while(1);
        }

        if (choice == 2) {
            con_printf("Writing payload\n");
            write_payload();
            bmc_shut_down();
            while(1);
        }

        /* Sector tests */
        if (choice == 3) {
            con_printf("Running sector tests\n");
            test_minor_loops();
            HAL_Delay(1500);
            continue;
        }

        /* Major loop test */
        if (choice == 4) {
            con_printf("Testing major loop\n");
            test_major_loop();
            HAL_Delay(1500);
            continue;
        }
    }
}

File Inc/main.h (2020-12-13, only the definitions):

#define LCD_E_Pin GPIO_PIN_13
#define LCD_E_GPIO_Port GPIOC
#define LCD_DI_Pin GPIO_PIN_14
#define LCD_DI_GPIO_Port GPIOC
#define LCD_CS2_Pin GPIO_PIN_15
#define LCD_CS2_GPIO_Port GPIOC
#define LCD_D0_Pin GPIO_PIN_0
#define LCD_D0_GPIO_Port GPIOA
#define LCD_D1_Pin GPIO_PIN_1
#define LCD_D1_GPIO_Port GPIOA
#define LCD_D2_Pin GPIO_PIN_2
#define LCD_D2_GPIO_Port GPIOA
#define LCD_D3_Pin GPIO_PIN_3
#define LCD_D3_GPIO_Port GPIOA
#define LCD_D4_Pin GPIO_PIN_4
#define LCD_D4_GPIO_Port GPIOA
#define LCD_D5_Pin GPIO_PIN_5
#define LCD_D5_GPIO_Port GPIOA
#define LCD_D6_Pin GPIO_PIN_6
#define LCD_D6_GPIO_Port GPIOA
#define LCD_D7_Pin GPIO_PIN_7
#define LCD_D7_GPIO_Port GPIOA
#define LCD_CS1_Pin GPIO_PIN_0
#define LCD_CS1_GPIO_Port GPIOB
#define CX_EN_Pin GPIO_PIN_2
#define CX_EN_GPIO_Port GPIOB
#define CYB_Pin GPIO_PIN_12
#define CYB_GPIO_Port GPIOB
#define CXA_Pin GPIO_PIN_13
#define CXA_GPIO_Port GPIOB
#define CYA_Pin GPIO_PIN_14
#define CYA_GPIO_Port GPIOB
#define CXB_Pin GPIO_PIN_15
#define CXB_GPIO_Port GPIOB
#define ENC_A_Pin GPIO_PIN_8
#define ENC_A_GPIO_Port GPIOA
#define ENC_B_Pin GPIO_PIN_9
#define ENC_B_GPIO_Port GPIOA
#define ENC_BUTTON_Pin GPIO_PIN_10
#define ENC_BUTTON_GPIO_Port GPIOA
#define BUBBLE_DETECT_Pin GPIO_PIN_12
#define BUBBLE_DETECT_GPIO_Port GPIOA
#define DRIVE_STATE_Pin GPIO_PIN_15
#define DRIVE_STATE_GPIO_Port GPIOA
#define CY_EN_Pin GPIO_PIN_3
#define CY_EN_GPIO_Port GPIOB
#define FUNC_GEN_Pin GPIO_PIN_4
#define FUNC_GEN_GPIO_Port GPIOB
#define SAFETY_Pin GPIO_PIN_5
#define SAFETY_GPIO_Port GPIOB
#define FUNC_ANN_Pin GPIO_PIN_6
#define FUNC_ANN_GPIO_Port GPIOB
#define FUNC_XOUT_Pin GPIO_PIN_7
#define FUNC_XOUT_GPIO_Port GPIOB
#define FUNC_XIN_Pin GPIO_PIN_8
#define FUNC_XIN_GPIO_Port GPIOB

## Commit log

2020-12-13 uart: Deal with newlines
2020-12-13 read: Take detector track length into account
2020-12-13 Transfer function and power state
2020-12-13 Switch to EXTI-based detection
    This frees up a timer
2020-12-13 music: Make music interrupt-driven
2020-12-13 bmc: Disable/enable interrupts during sequence runs
2020-12-13 main: Stop messing with interrupts
2020-12-13 Implement block I/O with error fallback
    [block_io.c]
2020-12-13 Moar better error reporting
    [app_main.c, block_io.c]
2020-12-13 Retry the transfer operation
    Sometimes, transfer will fail, but we can read the failed
    sector twice, to transfer out the stragglers and OR them
    wit the bubbles we transferred out the first time.
    [block_io.c]
2020-12-13 Move to UART2, to free up Timer1
2020-12-13 Move to UART3
    This allows A0-A7 to be open
2020-12-13 drivers: Add encoder
    Add a basic rotary encoder driver.
2020-12-13 gfx: Add a main menu
    Add a top-level menu for the entire device.
2020-12-13 Fix off-by-one minor loop bug
    [bmc.c, selftest.c]
2020-12-13 Switch to active-high function driver logic
    And fuck with timings accordingly.
2020-12-13 Reconfigure pins for actual PCB
2020-12-13 payload: Switch to Tetris
2020-12-13 payload: Switch to back to Snake
    This reverts commit e15a9e2b4ee967067b3f27bd34477ae7714afe13.
2020-12-13 doc: Add historical documentation
    Add the historical documentation that was used to determine
    how to actually control the bubble memory module. This was
    scattered over the internet, in obscure archives. Without
    this documentation, this project would not have been
    possible. By gathering it in one place, I hope to help the
    next person who decides to play with these devices.
2020-12-13 design: Check in schematics / layout / gerbers
    Check in the hardware design files for the final board,
    along with PNGs of the schematic and layout. This version
    differs very slightly from the v1.0 that was manufactured,
    in that some silkscreen elements were slightly tweaked.
    [bmc.brd, bmc.sch]
2022-02-24 doc: Add photos for documentation
    Add some photos of the project at various build stages.

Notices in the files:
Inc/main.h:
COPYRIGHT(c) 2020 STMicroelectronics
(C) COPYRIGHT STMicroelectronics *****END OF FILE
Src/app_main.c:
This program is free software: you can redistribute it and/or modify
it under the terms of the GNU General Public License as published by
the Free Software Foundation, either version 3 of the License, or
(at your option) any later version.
